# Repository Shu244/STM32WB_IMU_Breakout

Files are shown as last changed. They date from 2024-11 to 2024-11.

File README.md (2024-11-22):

## Overview

This repo contains a 4 layer PCB (signal - ground - ground - power) that contains BLE, IMU, and battery capabilities using
a STM32WB MCU.

This project extends Phil Lab's two part tutorial:

1) Schematic: https://www.youtube.com/watch?v=nkHFoxe0mrU&t=6654s
2) PCB: https://www.youtube.com/watch?v=PlXd3lLZ4vc

This project includes the following additions to the tutorial:

1) Charging IC and peripherals to support LiPo battery (IC was selected to support power path i.e. provide power while charging)
2) ST IMU chip

## Results

### PCB Board

Top View:

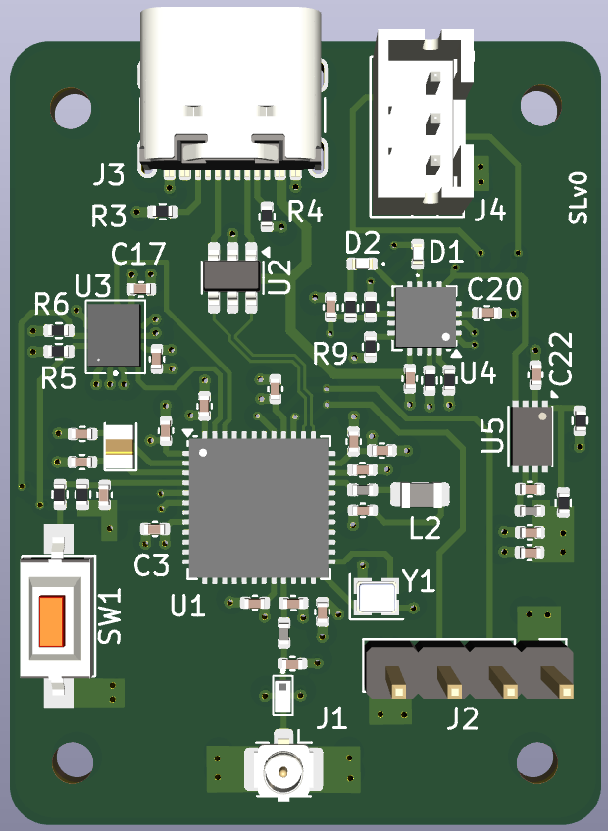
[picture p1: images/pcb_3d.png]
Final PCB Board, Top View


Bottom View:

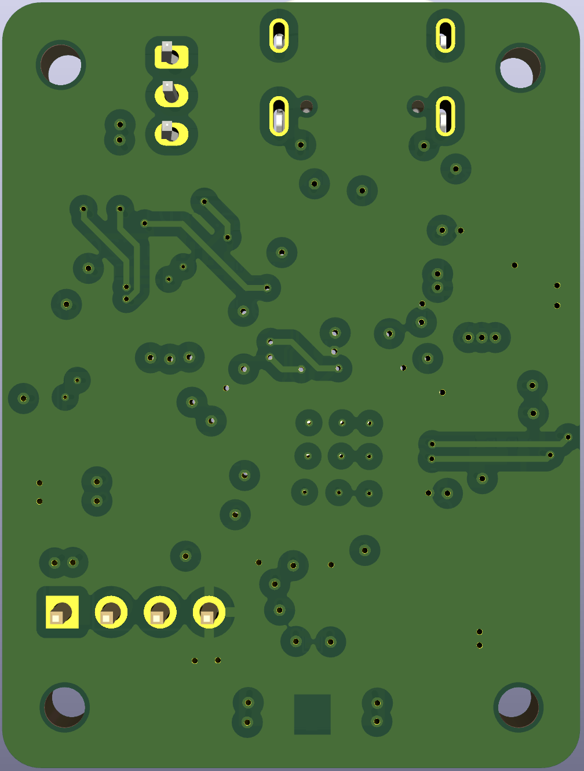
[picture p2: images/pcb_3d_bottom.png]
Final PCB Board, Bottom View


### PCB Routing

Top View:

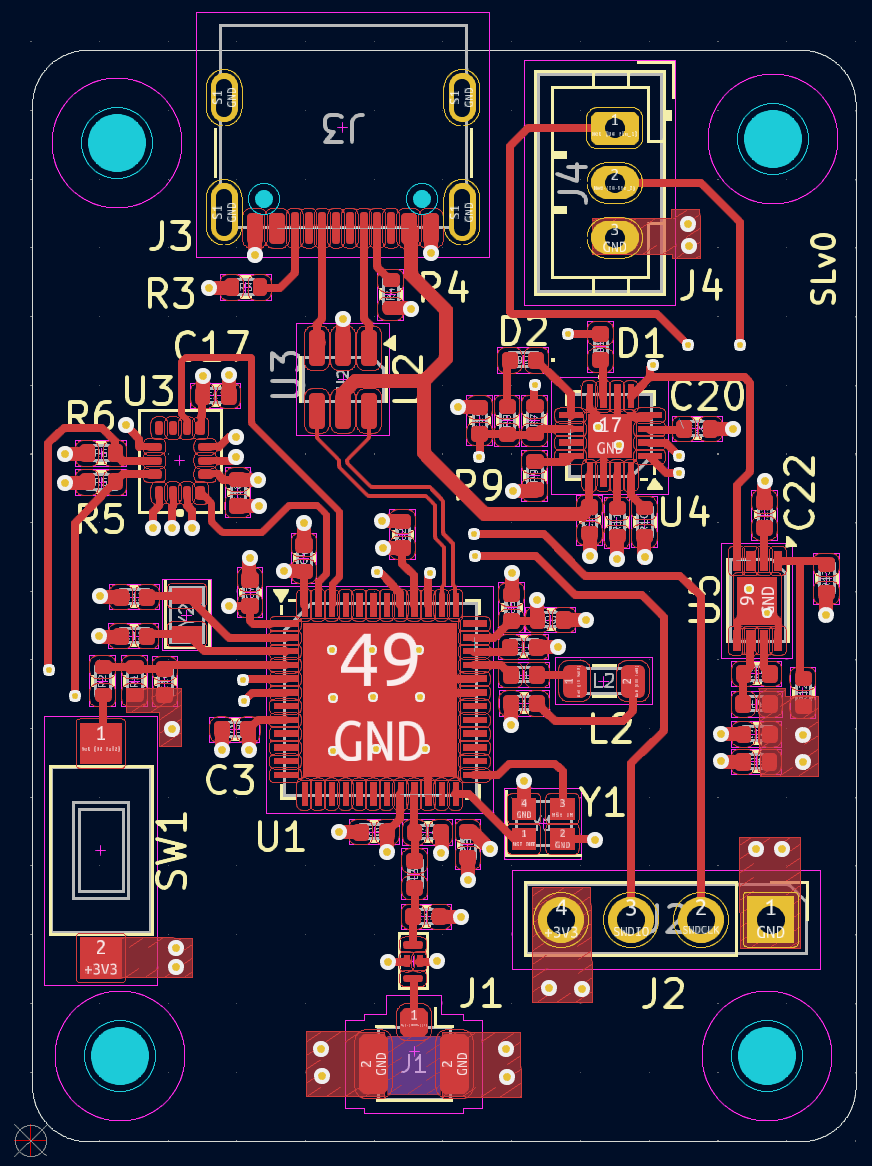
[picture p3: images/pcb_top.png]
Top of PCB board


Bottom View:

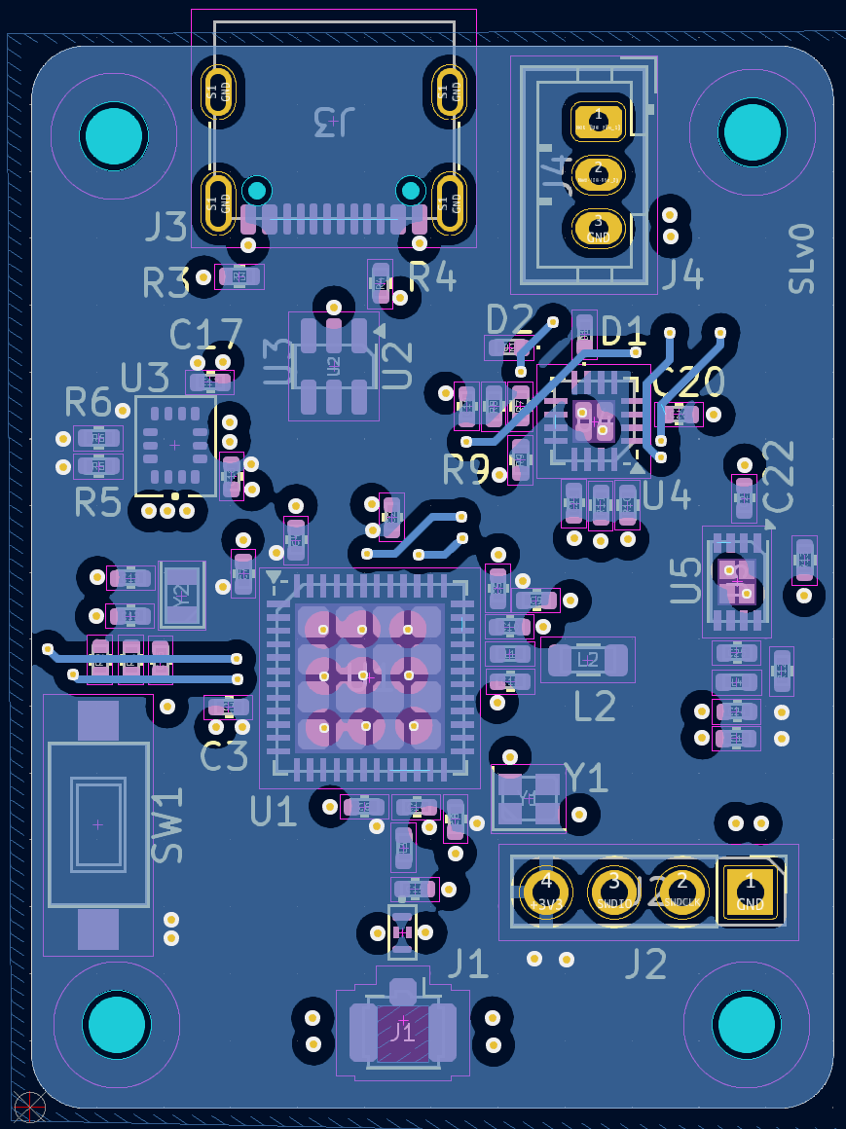
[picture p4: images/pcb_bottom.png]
Bottom of PCB board


### Schematic

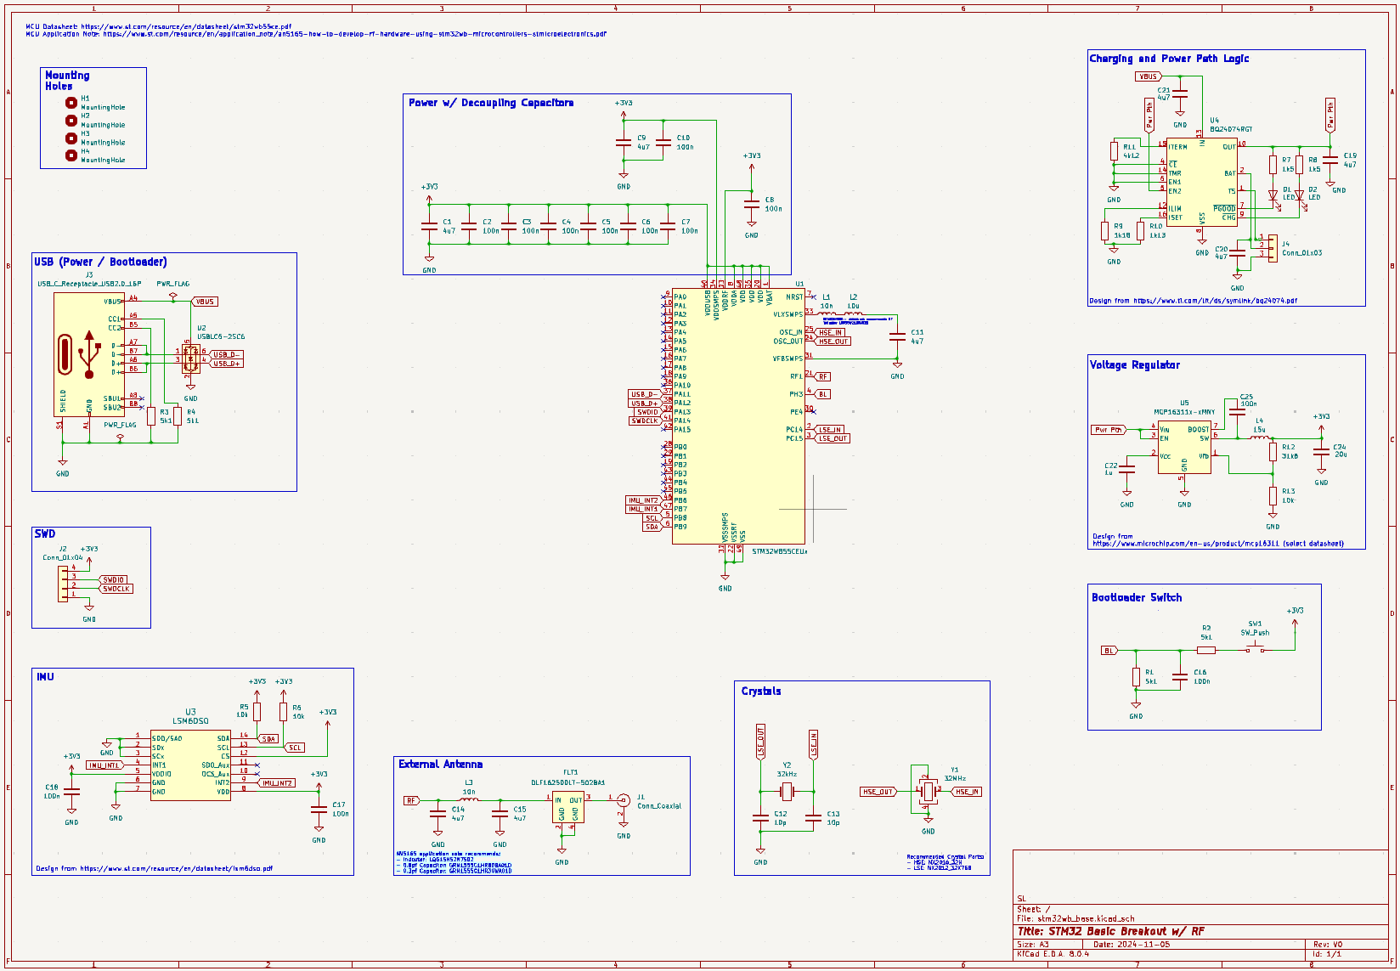
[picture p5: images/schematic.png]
Schematic of Board


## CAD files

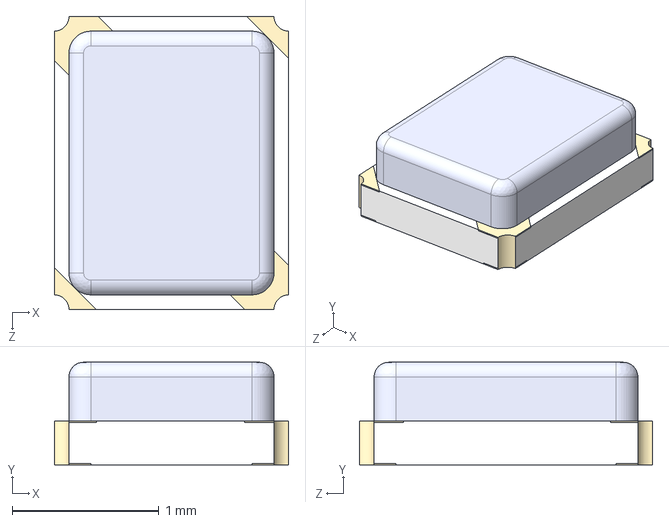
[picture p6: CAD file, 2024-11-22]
models/XRCGB32M000F2P01R0.step
1.60 x 0.7 x 2.00 mm

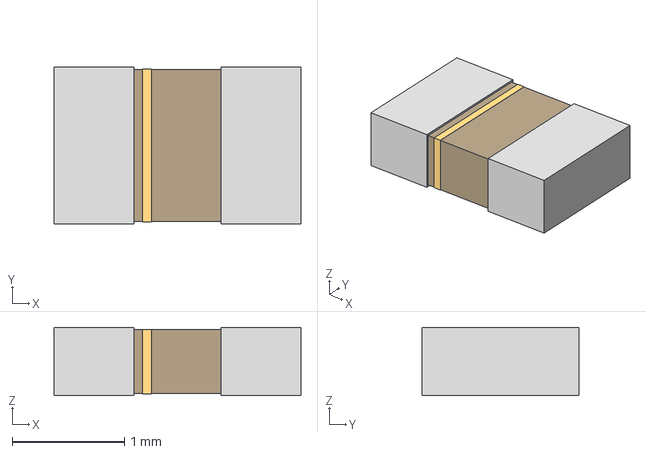
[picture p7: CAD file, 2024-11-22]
models/FC-12M32_7680KA-A3_EPS.step
2.20 x 1.40 x 0.61 mm

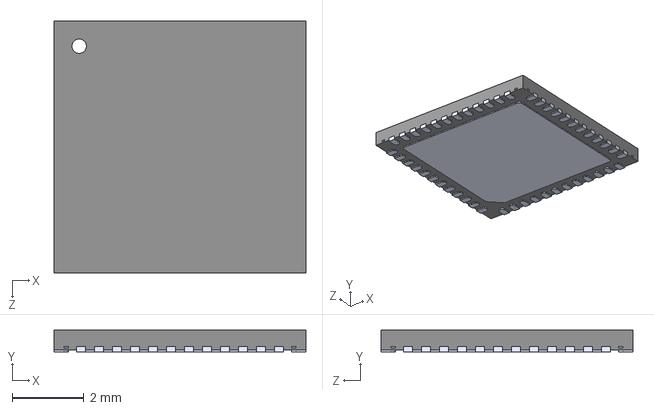
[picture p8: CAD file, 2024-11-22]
models/STM32WB55CEU6.step
7.00 x 0.6 x 7.00 mm

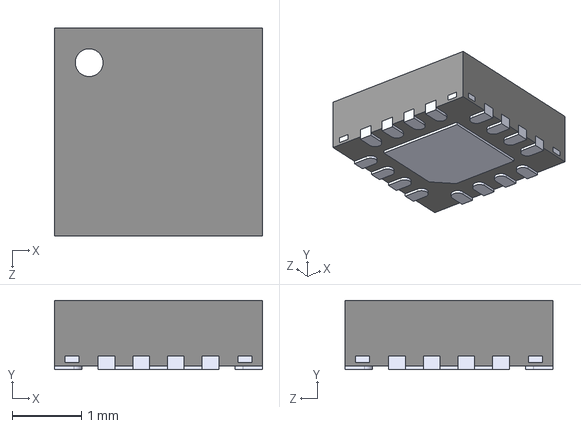
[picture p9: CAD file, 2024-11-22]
models/BQ24074RGTR.step
3.00 x 1.00 x 3.00 mm

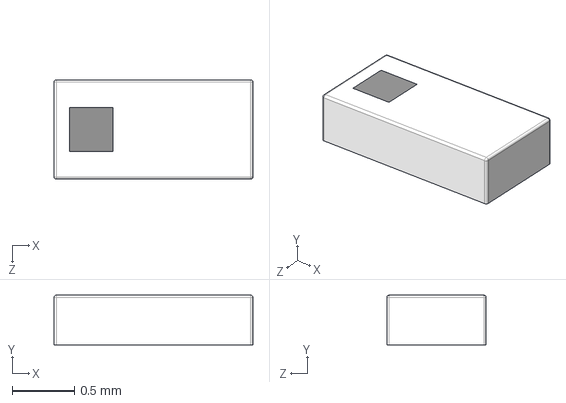
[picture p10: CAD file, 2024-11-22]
models/DLF162500LT-5028A1.STEP
1.60 x 0.4 x 0.8 mm

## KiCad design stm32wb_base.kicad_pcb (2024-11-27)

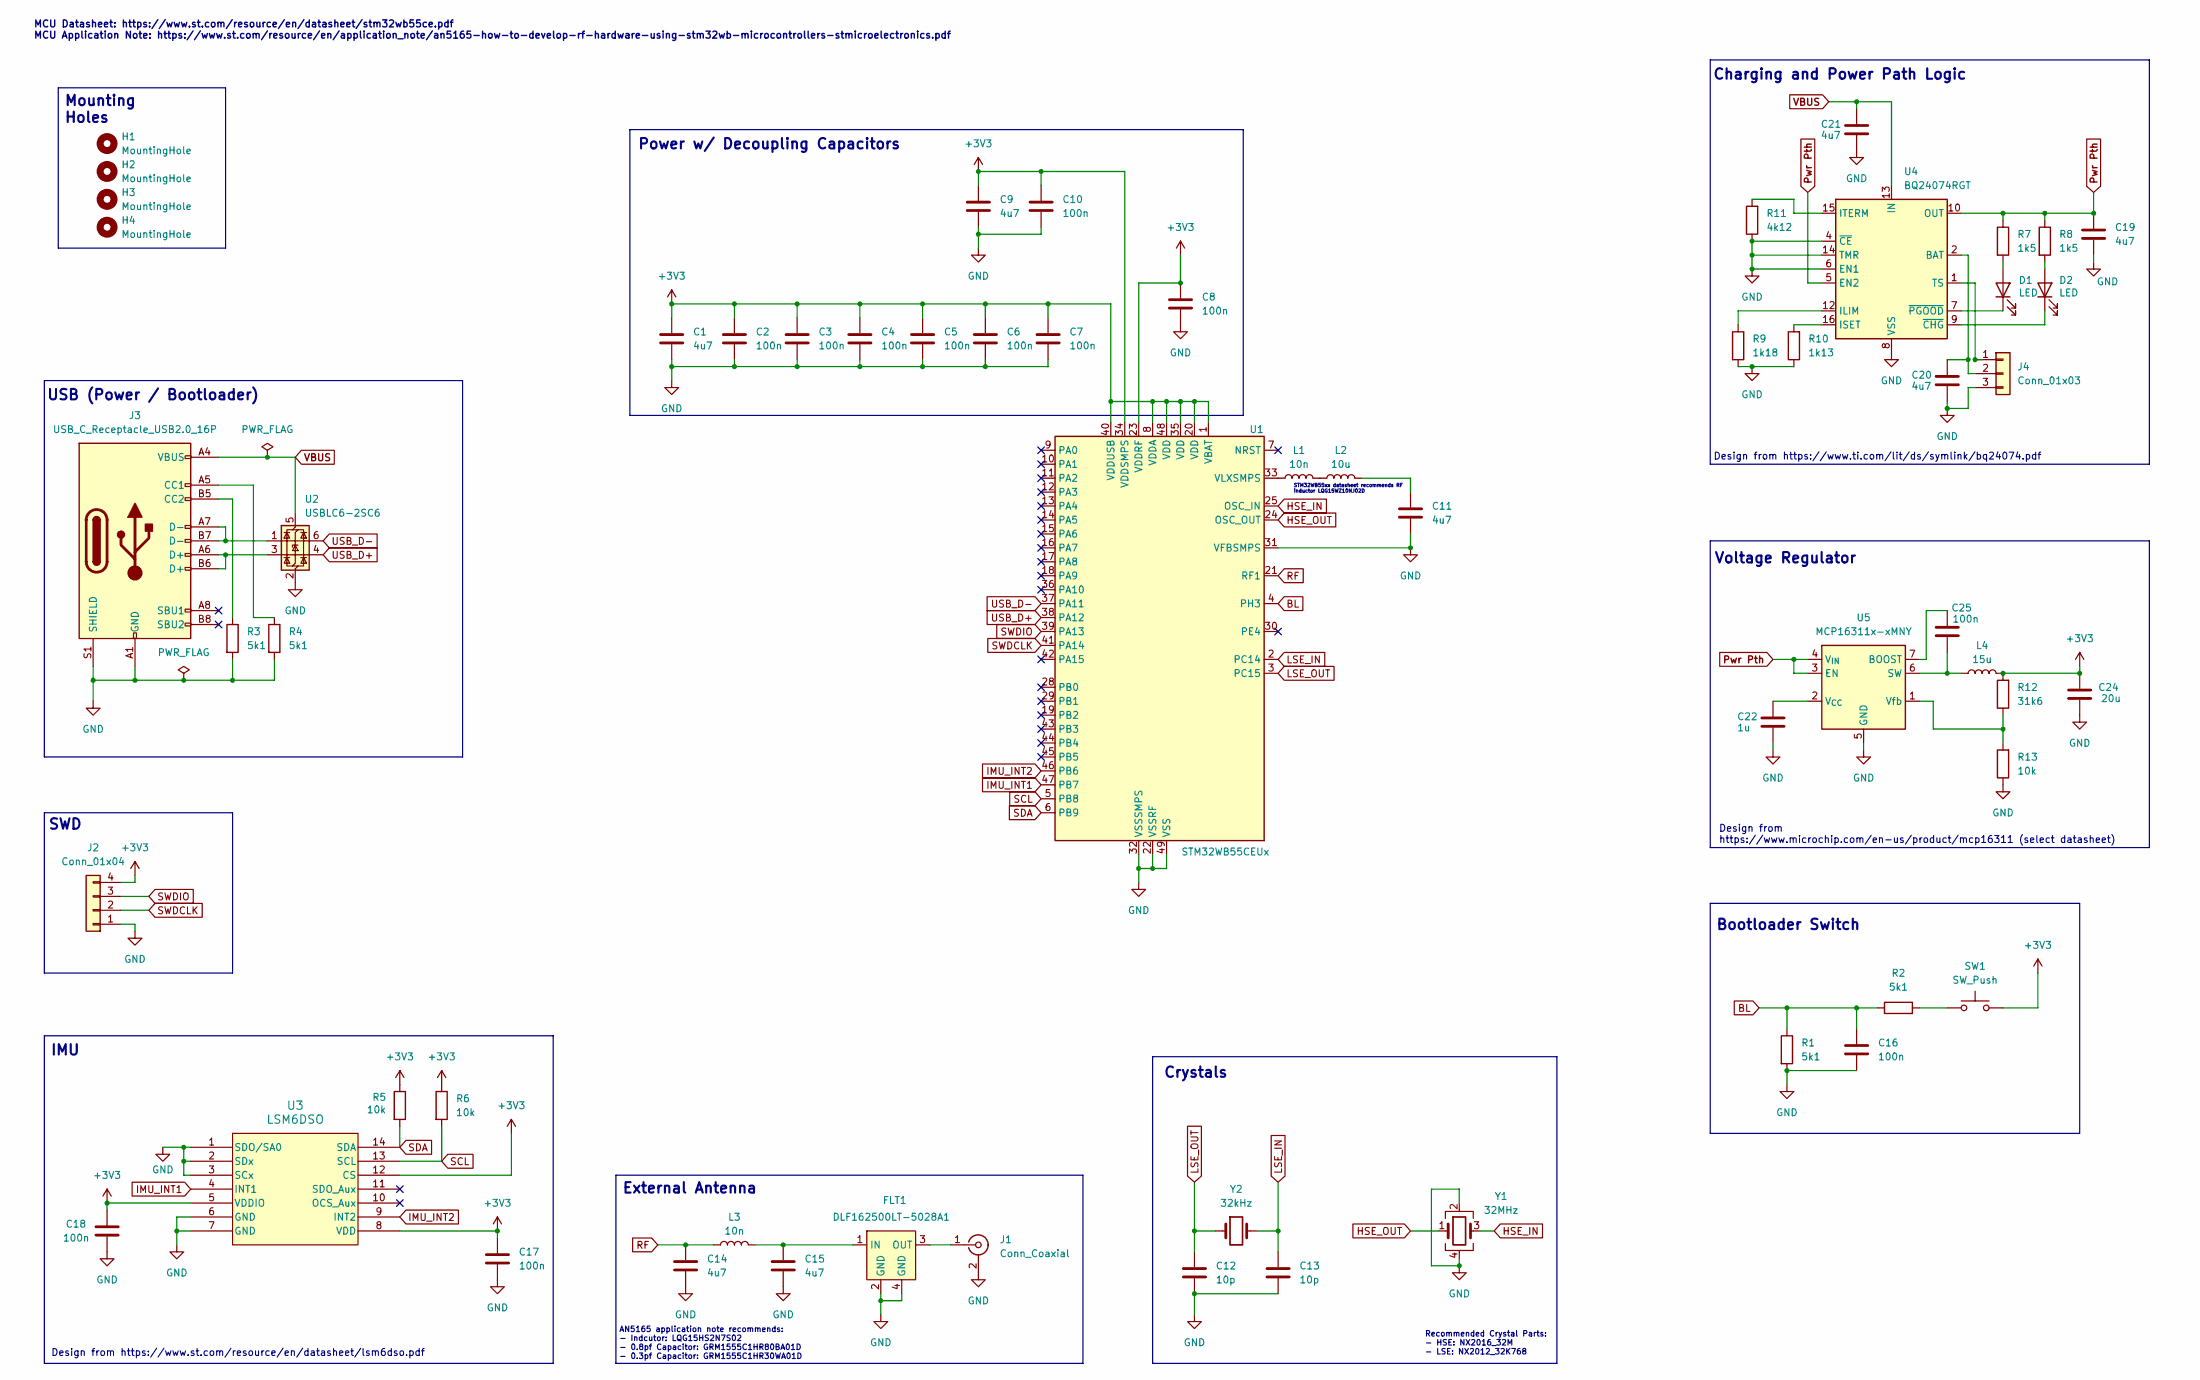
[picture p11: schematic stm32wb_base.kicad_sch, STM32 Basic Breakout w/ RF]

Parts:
C1, C9, C11, C14, C15, C19, C20, C21: 4u7; C_0402_1005Metric
C2, C3, C4, C5, C6, C7, C8, C10, C16, C17, C18, C25: 100n; C_0402_1005Metric
C12, C13: 10p; C_0402_1005Metric
C22: 1u; C_0402_1005Metric
C24: 20u; C_0402_1005Metric
D1, D2: LED; LED_0402_1005Metric
FLT1: DLF162500LT-5028A1
H1, H2, H3, H4: MountingHole; MountingHole_2.1mm
J1: Conn_Coaxial; U.FL_Hirose_U.FL-R-SMT-1_Vertical
J2: Conn_01x04; PinHeader_1x04_P2.54mm_Vertical
J3: USB_C_Receptacle_USB2.0_16P; USB_C_Receptacle_GCT_USB4105-xx-A_16P_TopMnt_Horizontal
J4: Conn_01x03; JST_PH_B3B-PH-K_1x03_P2.00mm_Vertical
L1, L3: 10n; L_0402_1005Metric
L2: 10u; L_0805_2012Metric
L4: 15u; L_0402_1005Metric
R1, R2, R3, R4: 5k1; R_0402_1005Metric
R5, R6, R13: 10k; R_0402_1005Metric
R7, R8: 1k5; R_0402_1005Metric
R9: 1k18; R_0402_1005Metric
R10: 1k13; R_0402_1005Metric
R11: 4k12; R_0402_1005Metric
R12: 31k6; R_0402_1005Metric
SW1: SW_Push; SW_SPST_CK_RS282G05A3
U1: STM32WB55CEUx; QFN-48-1EP_7x7mm_P0.5mm_EP5.6x5.6mm
U2: USBLC6-2SC6; SOT-23-6
U3: LSM6DSO
U4: BQ24074RGT; VQFN-16-1EP_3x3mm_P0.5mm_EP1.6x1.6mm
U5: MCP16311x-xMNY; DFN-8-1EP_3x2mm_P0.5mm_EP1.75x1.45mm
Y1: 32MHz; Crystal_SMD_2016-4Pin_2.0x1.6mm
Y2: 32kHz; Crystal_SMD_2012-2Pin_2.0x1.2mm

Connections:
+3V3: C1.1, C2.1, C3.1, C4.1, C5.1, C6.1, C7.1, C8.1, C9.1, C10.1, C17.1, C18.1, C24.1, J2.4, L4.2, R5.1, R6.1, R12.2, SW1.2, U1.1 (VBAT), U1.8 (VDDA), U1.20 (VDD), U1.23 (VDDRF), U1.34 (VDDSMPS), U1.35 (VDD), U1.40 (VDDUSB), U1.48 (VDD), U3.5 (VDDIO), U3.8 (VDD), U3.12 (CS)
BL: C16.1, R1.1, R2.1, U1.4 (PH3)
GND: C1.2, C2.2, C3.2, C4.2, C5.2, C6.2, C7.2, C8.2, C9.2, C10.2, C11.2, C12.2, C13.2, C14.2, C15.2, C16.2, C17.2, C18.2, C19.2, C20.2, C21.2, C22.2, C24.2, FLT1.2 (GND), FLT1.4 (GND), J1.2 (Ext), J2.1, J3.A1 (GND), J3.A12 (GND), J3.B1 (GND), J3.B12 (GND), J3.S1 (SHIELD), J4.3, R1.2, R3.2, R4.2, R9.2, R10.1, R11.1, R13.1, U1.22 (VSSRF), U1.31 (VFBSMPS), U1.32 (VSSSMPS), U1.49 (VSS), U2.2 (GND), U3.1 (SDO/SA0), U3.2 (SDx), U3.3 (SCx), U3.6 (GND), U3.7 (GND), U4.4 (~CE), U4.6 (EN1), U4.8 (VSS), U4.14 (TMR), U4.17 (VSS), U5.5 (GND), U5.8 (GND), U5.9 (GND), Y1.2, Y1.4
HSE_IN: U1.25 (OSC_IN), Y1.3
HSE_OUT: U1.24 (OSC_OUT), Y1.1
IMU_INT1: U1.47 (PB7), U3.4 (INT1)
IMU_INT2: U1.46 (PB6), U3.9 (INT2)
LSE_IN: C13.1, U1.2 (PC14), Y2.2
LSE_OUT: C12.1, U1.3 (PC15), Y2.1
unnamed: C11.1, L2.2
unnamed: D1.2 (A), R7.2
unnamed: D1.1 (K), U4.7 (~PGOOD)
unnamed: D2.2 (A), R8.2
unnamed: D2.1 (K), U4.9 (~CHG)
unnamed: C15.1, FLT1.1 (IN), L3.2
unnamed: FLT1.3 (OUT), J1.1 (In)
unnamed: J3.A5 (CC1), R4.1
unnamed: J3.B5 (CC2), R3.1
unnamed: J3.A6 (D+), J3.B6 (D+), U2.3 (I/O2)
unnamed: J3.A7 (D-), J3.B7 (D-), U2.1 (I/O1)
unnamed: J4.1, U4.1 (TS)
unnamed: C20.1, J4.2, U4.2 (BAT), U4.3 (BAT)
unnamed: L1.2, L2.1
unnamed: R2.2, SW1.1
unnamed: L1.1, U1.33 (VLXSMPS)
unnamed: R9.1, U4.12 (ILIM)
unnamed: R10.2, U4.16 (ISET)
unnamed: R11.2, U4.15 (ITERM)
unnamed: C25.2, U5.7 (BOOST)
unnamed: C25.1, L4.1, U5.6 (SW)
unnamed: C22.1, U5.2 (V_{CC})
unnamed: R12.1, R13.2, U5.1 (Vfb)
Pwr Pth: C19.1, R7.1, R8.1, U4.5 (EN2), U4.10 (OUT), U4.11 (OUT), U5.3 (EN), U5.4 (V_{IN})
RF: C14.1, L3.1, U1.21 (RF1)
SCL: R6.2, U1.5 (PB8), U3.13 (SCL)
SDA: R5.2, U1.6 (PB9), U3.14 (SDA)
SWDCLK: J2.2, U1.41 (PA14)
SWDIO: J2.3, U1.39 (PA13)
USB_D+: U1.38 (PA12), U2.4 (I/O2)
USB_D-: U1.37 (PA11), U2.6 (I/O1)
VBUS: C21.1, J3.A4 (VBUS), J3.A9 (VBUS), J3.B4 (VBUS), J3.B9 (VBUS), U2.5 (VBUS), U4.13 (IN)

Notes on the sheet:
Design from https://www.microchip.com/en-us/product/mcp16311 (select datasheet)
Charging and Power Path Logic
SWD
IMU
USB (Power / Bootloader)
Design from https://www.st.com/resource/en/datasheet/lsm6dso.pdf
Mounting Holes
MCU Datasheet: https://www.st.com/resource/en/datasheet/stm32wb55ce.pdf MCU Application Note: https://www.st.com/resource/en/application_note/an5165-how-to-develop-rf-hardware-using-stm32wb-microcontrollers-stmicroelectronics.pdf
Bootloader Switch
Power w/ Decoupling Capacitors
Design from https://www.ti.com/lit/ds/symlink/bq24074.pdf
STM32WB55xx datasheet recommends RF inductor LQG15WZ10NJ02D
Voltage Regulator
Recommended Crystal Parts: - HSE: NX2016_32M - LSE: NX2012_32K768
External Antenna
Crystals
AN5165 application note recommends: - Indcutor: LQG15HS2N7S02 - 0.8pf Capacitor: GRM1555C1HR80BA01D - 0.3pf Capacitor: GRM1555C1HR30WA01D

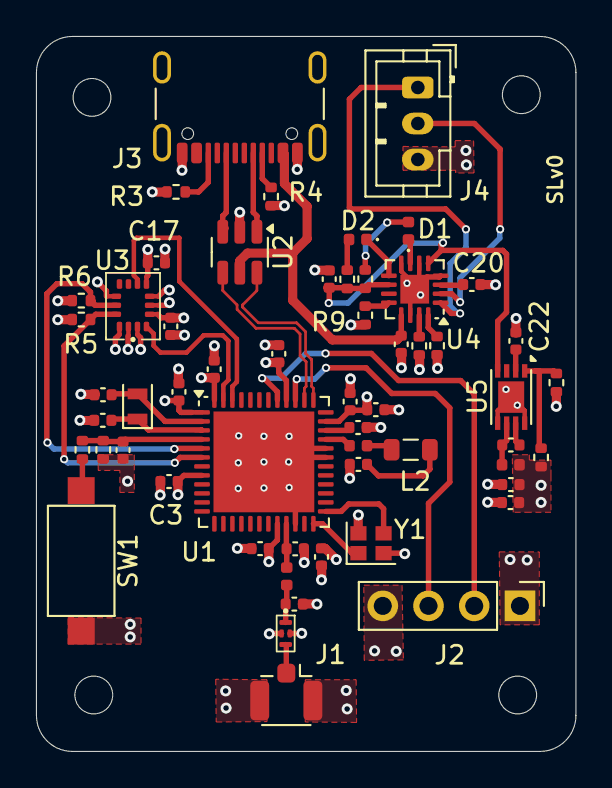
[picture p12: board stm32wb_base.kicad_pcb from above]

Board: 4 copper layers, 30.0 x 39.7 mm, 60 parts (0 on the bottom side), 41 nets.

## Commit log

2024-11-22 STM32WB breakout board with charger and IMU
    [BQ24074RGTR.step, DLF162500LT-5028A1.STEP, FC-12M32_7680KA-A3_EPS.step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]
2024-11-22 Added readme and manufactoring files
    [stm32wb_base-B_Cu.gbr, stm32wb_base-B_Mask.gbr, stm32wb_base-B_Paste.gbr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]
2024-11-22 update schematic image
2024-11-22 update company and version
    [stm32wb_base.kicad_sch]
2024-11-26 updated schematic image
    [stm32wb_base.kicad_sch]
2024-11-27 updated vias on thermal pads
    [stm32wb_base.kicad_pcb]
